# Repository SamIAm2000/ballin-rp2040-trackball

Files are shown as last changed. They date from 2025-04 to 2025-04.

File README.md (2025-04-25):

# ballin

**An open-source 4-button USB trackball powered by the RP2040.**

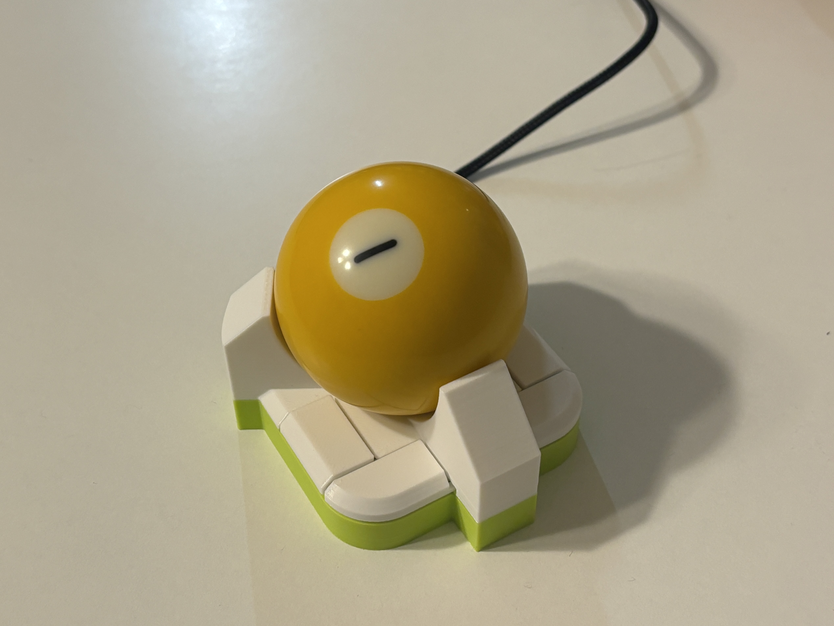
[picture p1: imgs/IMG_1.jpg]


Uses [Jacek Fedorynski's](https://github.com/jfedor2) original PMW3360 trackball firmware and PCB [RP2040+PMW3360](https://github.com/jfedor2/rp2040-pmw3360)

3D models remixed from [here](https://www.printables.com/model/267954-trackball-15de/comments)

The four buttons map to Left Mouse Button, Right Mouse Button, Mouse 4, and Mouse 5. The original model only had 2 buttons, which was not adequate to implement scrolling and swiping functionality on top of the basic left and right clicking.

With the addition of two other buttons, you can map software on your computer to enable scrolling and swiping behaviors when you hold certain mouse buttons. I'm personally a fan of using [Mac Mouse Fix](https://github.com/noah-nuebling/mac-mouse-fix) on all my Mac computers to map Mouse 5 to scrolling when dragged, and Mouse 4 to the 3 fingered swipe that allows you to switch between desktops and spaces and mission control. 

Alternatively, if you want hardware scrolling programmed on the trackball instead of your computer, you can also modify the source code for the trackball. 

## Fabrication
Requires:

- 57.2mm billiard ball
- PMW3360 optical sensor
- PCB from here: https://github.com/jfedor2/rp2040-pmw3360
- 4 micro switches for mice
- 3 2.5mm zirconium oxide (or silicon nitride) bearing balls
- 2 M2x5 screws for securing the switch plates to base 
- 4 M3x4 screws for securing PCB to base
- 3 M3x12 flat head screws
- USB cable *Note: this should be a USB-A cable with the standard 4 wires. Using a USB-C cable might work, but since USB-C generally relies on a handshake before providing power, the trackball would not directly work if you plugged it into your computer with a USB-C cord unless you have a dongle in between.*

### 3D printing
I 3D printed the parts at .20 layer height, no supports needed. I used 40% sparse infill for the top part to get some rigidity and heft. The base I printed at standard 15% sparse infill. 

For the plates that hold the micro switchees, depending on your 3D printer's tolerances, the holes might not be big enough to fit the micro switch legs. I would suggest to first try widening them with some tweezers, if that doesn't work, adjust the X-Y hole compensation by + .1mm maybe. It's better for the holes to be tight and grip onto the switches well than to be too loose and have your switches wobble around. 

### Soldering button pins
Another thing to note is which pins on the PCB you solder your mouse buttons to. In the current compiled trackball.uf2, I have the pins for the buttons defined as thus below. If you use different pins, you would need to modify this code in [code/src/trackball.c](https://github.com/SamIAm2000/ballin-rp2040-trackball/blob/main/code/src/trackball.c)
```
#define TOP_LEFT 16 // Mouse 5
#define TOP_RIGHT 28 // Mouse 4
#define BOTTOM_LEFT 17 // Mouse 1
#define BOTTOM_RIGHT 26 // Mouse 2
```

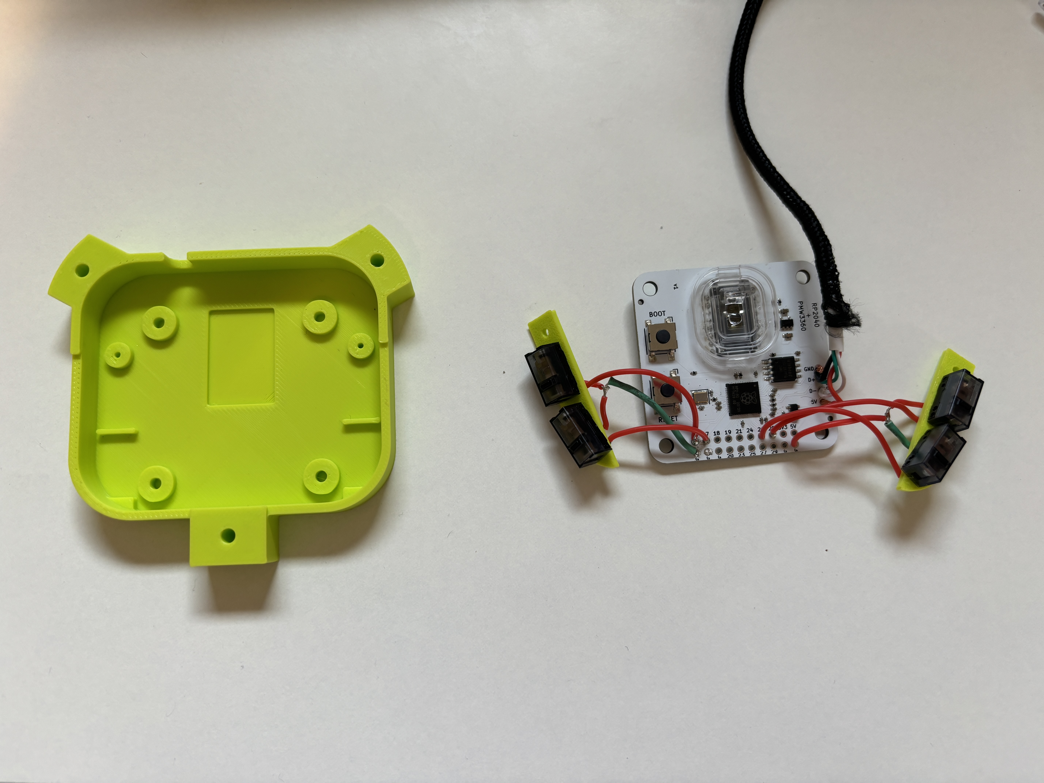
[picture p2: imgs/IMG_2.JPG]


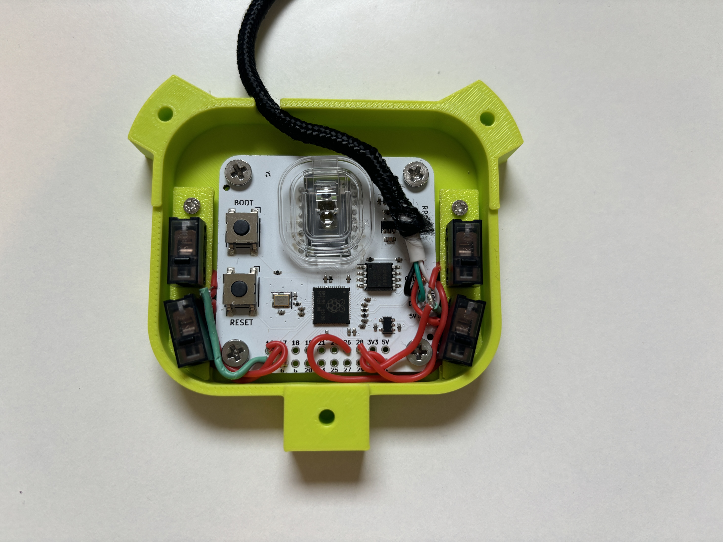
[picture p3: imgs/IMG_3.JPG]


## Compilation

You need Python and CMake installed. 

Once you've cloned this repository, run these commands in the ./code folder to create a build directory and compile.
```
mkdir build
cd build
cmake ..
make
```
The compiled file will be the `trackball.uf2` in the ./code/build/ folder.

## Flashing
To upload the compiled trackball.uf2 file from your computer to the trackball, plug in the USB cable from the trackball into your computer and hold boot, then press reset, then let go of both buttons. The trackball should appear in your list of devices. Drag and drop the .uf2 file on to the trackball.

## Demo
https://github.com/user-attachments/assets/3003e133-2ebc-4bb3-9a59-b019c4e8687f

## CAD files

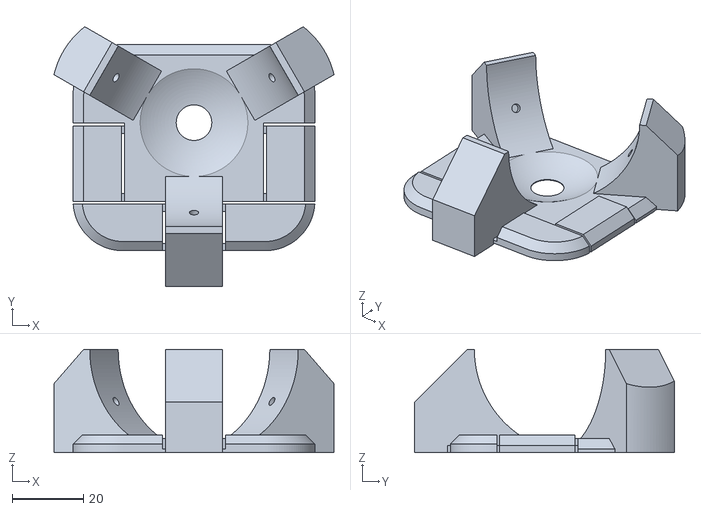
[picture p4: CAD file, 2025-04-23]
3d_models/ballin_top.stl
78.7 x 73.0 x 29.0

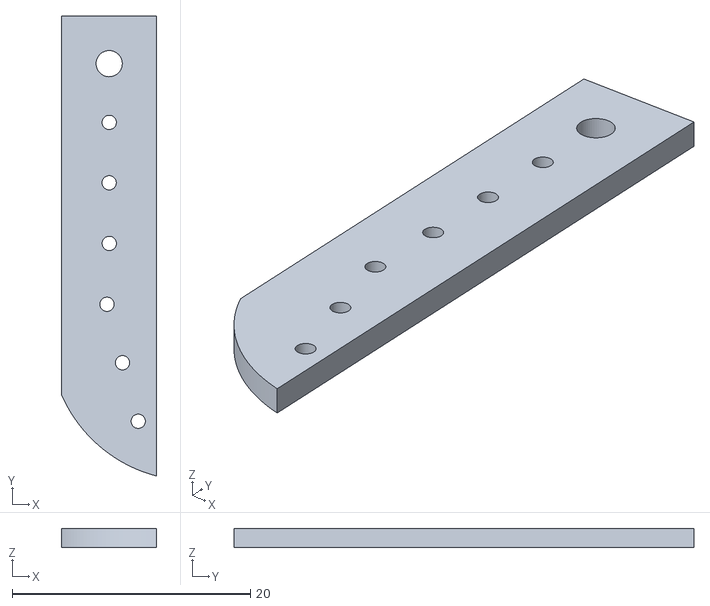
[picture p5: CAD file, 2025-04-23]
3d_models/ballin_plate.stl
7.97 x 38.6 x 1.60

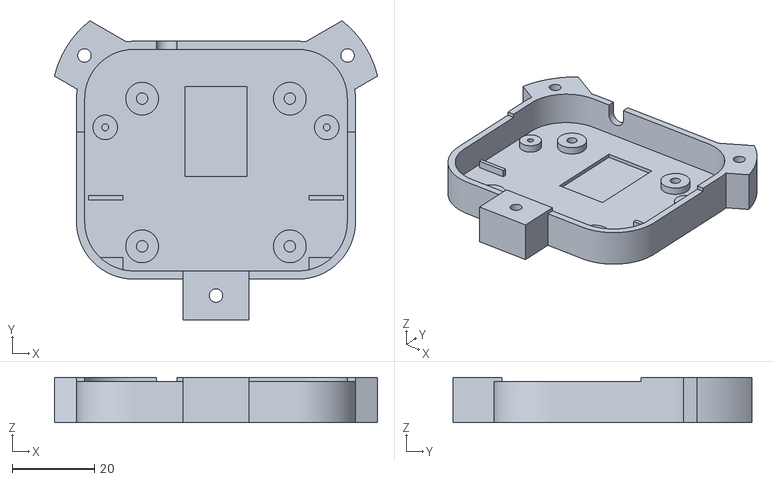
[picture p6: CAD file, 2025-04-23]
3d_models/ballin_base.stl
78.7 x 73.0 x 11.0

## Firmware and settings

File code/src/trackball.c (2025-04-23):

/*
 * The MIT License (MIT)
 *
 * Copyright (c) 2021 Jacek Fedorynski
 * Copyright (c) 2019 Ha Thach (tinyusb.org)
 *
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
 */

#include <stdlib.h>
#include <stdio.h>
#include <string.h>

#include "bsp/board.h"
#include "tusb.h"

#include "pico/stdlib.h"

#include "hardware/gpio.h"

#include "pmw3360.h"

#define TOP_LEFT 16 // Mouse 5
#define TOP_RIGHT 28 // Mouse 4
#define BOTTOM_LEFT 17 // Mouse 1
#define BOTTOM_RIGHT 26 // Mouse 2

// These IDs are bogus. If you want to distribute any hardware using this,
// you will have to get real ones.
#define USB_VID 0xCAFE
#define USB_PID 0xBABA

tusb_desc_device_t const desc_device = {
    .bLength = sizeof(tusb_desc_device_t),
    .bDescriptorType = TUSB_DESC_DEVICE,
    .bcdUSB = 0x0200,
    .bDeviceClass = 0x00,
    .bDeviceSubClass = 0x00,
    .bDeviceProtocol = 0x00,
    .bMaxPacketSize0 = CFG_TUD_ENDPOINT0_SIZE,

    .idVendor = USB_VID,
    .idProduct = USB_PID,
    .bcdDevice = 0x0100,

    .iManufacturer = 0x01,
    .iProduct = 0x02,
    .iSerialNumber = 0x00,

    .bNumConfigurations = 0x01};

uint8_t const desc_hid_report[] = {
    0x05, 0x01,       // USAGE_PAGE (Generic Desktop)
    0x09, 0x02,       // USAGE (Mouse)
    0xA1, 0x01,       // COLLECTION (Application)
    0x09, 0x01,       //   USAGE (Pointer)
    0xA1, 0x00,       //   COLLECTION (Physical)
    0x05, 0x09,       //     USAGE_PAGE (Button)
    0x19, 0x01,       //     USAGE_MINIMUM (1)
    0x29, 0x05,       //     USAGE_MAXIMUM (5)     
    0x15, 0x00,       //     LOGICAL_MINIMUM (0)
    0x25, 0x01,       //     LOGICAL_MAXIMUM (1)
    0x95, 0x05,       //     REPORT_COUNT (5)
    0x75, 0x01,       //     REPORT_SIZE (1)
    0x81, 0x02,       //     INPUT (Data,Var,Abs)
    0x95, 0x01,       //     REPORT_COUNT (1)
    0x75, 0x03,       //     REPORT_SIZE (3)       
    0x81, 0x03,       //     INPUT (Const,Var,Abs)
    0x05, 0x01,       //     USAGE_PAGE (Generic Desktop)
    0x09, 0x30,       //     USAGE (X)
    0x09, 0x31,       //     USAGE (Y)
    0x16, 0x00, 0x80, //     LOGICAL_MINIMUM(-32768)
    0x26, 0xff, 0x7f, //     LOGICAL_MAXIMUM(32767)
    0x75, 0x10,       //     REPORT_SIZE (16)
    0x95, 0x02,       //     REPORT_COUNT (2)
    0x81, 0x06,       //     INPUT (Data,Var,Rel)
    0xC0,             //   END_COLLECTION
    0xC0              // END COLLECTION
};

#define CONFIG_TOTAL_LEN (TUD_CONFIG_DESC_LEN + TUD_HID_DESC_LEN)
#define EPNUM_HID 0x81

uint8_t const desc_configuration[] = {
    // Config number, interface count, string index, total length, attribute, power in mA
    TUD_CONFIG_DESCRIPTOR(1, 1, 0, CONFIG_TOTAL_LEN, 0, 100),

    // Interface number, string index, protocol, report descriptor len, EP In address, size & polling interval
    TUD_HID_DESCRIPTOR(0, 0, HID_ITF_PROTOCOL_NONE, sizeof(desc_hid_report), EPNUM_HID, CFG_TUD_HID_EP_BUFSIZE, 1)};

char const *string_desc_arr[] = {
    (const char[]){0x09, 0x04}, // 0: is supported language is English (0x0409)
    "Trackball",                // 1: Manufacturer
    "Trackball",                // 2: Product
};

// HID report
typedef struct __attribute__((packed))
{
    uint8_t buttons;
    int16_t dx;
    int16_t dy;
} hid_report_t;

hid_report_t report;

void hid_task(void)
{
    int16_t dx;
    int16_t dy;

    if (!tud_hid_ready())
    {
        return;
    }

    pmw3360_get_deltas(&dx, &dy);

    report.dx = dx;
    report.dy = -dy;

    report.buttons = 0;

    if (!gpio_get(BOTTOM_LEFT))
        report.buttons |= 0x01; // Bit 0 = Left Click
    if (!gpio_get(BOTTOM_RIGHT))
        report.buttons |= 0x02; // Bit 1 = Right Click
    // if (!gpio_get(PIN_MMB))   report.buttons |= 0x04; // Bit 2 = Middle Click
    if (!gpio_get(TOP_RIGHT))
        report.buttons |= 0x08; // Bit 3 = Mouse Button 4 - 3 finger swipe
    if (!gpio_get(TOP_LEFT))
        report.buttons |= 0x10; // Bit 4 = Mouse Button 5 - scroll

    tud_hid_report(0, &report, sizeof(report));
}

void pin_init(uint pin)
{
    gpio_init(pin);
    gpio_set_dir(pin, GPIO_IN);
    gpio_pull_up(pin);
}

void pins_init(void)
{
    pin_init(TOP_LEFT);
    pin_init(TOP_RIGHT);
    pin_init(BOTTOM_LEFT);
    pin_init(BOTTOM_RIGHT);
}

void report_init(void)
{
    memset(&report, 0, sizeof(report));
}

int main(void)
{
    stdio_init_all();
    board_init();
    pins_init();
    pmw3360_init();
    report_init();
    tusb_init();

    pmw3360_set_cpi(800);

    while (1)
    {
        tud_task(); // tinyusb device task
        hid_task();
    }

    return 0;
}

// Invoked when received GET DEVICE DESCRIPTOR
// Application return pointer to descriptor
uint8_t const *tud_descriptor_device_cb(void)
{
    return (uint8_t const *)&desc_device;
}

// Invoked when received GET HID REPORT DESCRIPTOR
// Application return pointer to descriptor
// Descriptor contents must exist long enough for transfer to complete
uint8_t const *tud_hid_descriptor_report_cb(uint8_t itf)
{
    return desc_hid_report;
}

// Invoked when received GET_REPORT control request
// Application must fill buffer report's content and return its length.
// Return zero will cause the stack to STALL request
uint16_t tud_hid_get_report_cb(uint8_t itf, uint8_t report_id, hid_report_type_t report_type, uint8_t *buffer, uint16_t reqlen)
{
    return 0;
}

// Invoked when received SET_REPORT control request or
// received data on OUT endpoint ( Report ID = 0, Type = 0 )
void tud_hid_set_report_cb(uint8_t itf, uint8_t report_id, hid_report_type_t report_type, uint8_t const *buffer, uint16_t bufsize)
{
}

// Invoked when received GET CONFIGURATION DESCRIPTOR
// Application return pointer to descriptor
// Descriptor contents must exist long enough for transfer to complete
uint8_t const *tud_descriptor_configuration_cb(uint8_t index)
{
    return desc_configuration;
}

static uint16_t _desc_str[32];

// Invoked when received GET STRING DESCRIPTOR request
// Application return pointer to descriptor, whose contents must exist long enough for transfer to complete
uint16_t const *tud_descriptor_string_cb(uint8_t index, uint16_t langid)
{
    uint8_t chr_count;

    if (index == 0)
    {
        memcpy(&_desc_str[1], string_desc_arr[0], 2);
        chr_count = 1;
    }
    else
    {
        // Note: the 0xEE index string is a Microsoft OS 1.0 Descriptors.
        // https://docs.microsoft.com/en-us/windows-hardware/drivers/usbcon/microsoft-defined-usb-descriptors

        if (!(index < sizeof(string_desc_arr) / sizeof(string_desc_arr[0])))
            return NULL;

        const char *str = string_desc_arr[index];

        // Cap at max char
        chr_count = strlen(str);
        if (chr_count > 31)
            chr_count = 31;

        // Convert ASCII string into UTF-16
        for (uint8_t i = 0; i < chr_count; i++)
        {
            _desc_str[1 + i] = str[i];
        }
    }

    // first byte is length (including header), second byte is string type
    _desc_str[0] = (TUSB_DESC_STRING << 8) | (2 * chr_count + 2);

    return _desc_str;
}

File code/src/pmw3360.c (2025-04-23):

// derived from https://github.com/mrjohnk/PMW3360DM-T2QU

#include "hardware/gpio.h"
#include "hardware/spi.h"

#include "srom.h"

#include <pico/time.h>

#define SPI_PORT spi0

#define PIN_MISO 4
#define PIN_CS   9
#define PIN_SCK  2
#define PIN_MOSI 3

// Registers
#define Product_ID  0x00
#define Revision_ID 0x01
#define Motion  0x02
#define Delta_X_L 0x03
#define Delta_X_H 0x04
#define Delta_Y_L 0x05
#define Delta_Y_H 0x06
#define SQUAL 0x07
#define Raw_Data_Sum  0x08
#define Maximum_Raw_data  0x09
#define Minimum_Raw_data  0x0A
#define Shutter_Lower 0x0B
#define Shutter_Upper 0x0C
#define Control 0x0D
#define Config1 0x0F
#define Config2 0x10
#define Angle_Tune  0x11
#define Frame_Capture 0x12
#define SROM_Enable 0x13
#define Run_Downshift 0x14
#define Rest1_Rate_Lower  0x15
#define Rest1_Rate_Upper  0x16
#define Rest1_Downshift 0x17
#define Rest2_Rate_Lower  0x18
#define Rest2_Rate_Upper  0x19
#define Rest2_Downshift 0x1A
#define Rest3_Rate_Lower  0x1B
#define Rest3_Rate_Upper  0x1C
#define Observation 0x24
#define Data_Out_Lower  0x25
#define Data_Out_Upper  0x26
#define Raw_Data_Dump 0x29
#define SROM_ID 0x2A
#define Min_SQ_Run  0x2B
#define Raw_Data_Threshold  0x2C
#define Config5 0x2F
#define Power_Up_Reset  0x3A
#define Shutdown  0x3B
#define Inverse_Product_ID  0x3F
#define LiftCutoff_Tune3  0x41
#define Angle_Snap  0x42
#define LiftCutoff_Tune1  0x4A
#define Motion_Burst  0x50
#define LiftCutoff_Tune_Timeout 0x58
#define LiftCutoff_Tune_Min_Length  0x5A
#define SROM_Load_Burst 0x62
#define Lift_Config 0x63
#define Raw_Data_Burst  0x64
#define LiftCutoff_Tune2  0x65

void cs_select() {
    asm volatile ("nop \n nop \n nop");
    gpio_put(PIN_CS, 0);        // Active low
    asm volatile ("nop \n nop \n nop");
}

void cs_deselect() {
    asm volatile ("nop \n nop \n nop");
    gpio_put(PIN_CS, 1);
    asm volatile ("nop \n nop \n nop");
}

uint8_t read_register(uint8_t reg_addr) {
    cs_select();

    // send adress of the register, with MSBit = 0 to indicate it's a read
    uint8_t x = reg_addr & 0x7f;
    spi_write_blocking(SPI_PORT, &x, 1);
    sleep_us(100);              // tSRAD
    // read data
    uint8_t data;
    spi_read_blocking(SPI_PORT, 0, &data, 1);

    sleep_us(1);                // tSCLK-NCS for read operation is 120ns
    cs_deselect();
    sleep_us(19);               // tSRW/tSRR (=20us) minus tSCLK-NCS

    return data;
}

void write_register(uint8_t reg_addr, uint8_t data) {
    cs_select();

    // send adress of the register, with MSBit = 1 to indicate it's a write
    uint8_t x = reg_addr | 0x80;
    spi_write_blocking(SPI_PORT, &x, 1);
    // send data
    spi_write_blocking(SPI_PORT, &data, 1);

    sleep_us(20);               // tSCLK-NCS for write operation
    cs_deselect();
    sleep_us(100);              // tSWW/tSWR (=120us) minus tSCLK-NCS. Could be shortened, but is looks like a safe lower bound 
}

void upload_firmware() {
    // send the firmware to the chip, cf p.18 of the datasheet

    // Write 0 to Rest_En bit of Config2 register to disable Rest mode.
    write_register(Config2, 0x20);

    // write 0x1d in SROM_enable reg for initializing
    write_register(SROM_Enable, 0x1d);

    // wait for more than one frame period
    sleep_ms(10);               // assume that the frame rate is as low as 100fps... even if it should never be that low

    // write 0x18 to SROM_enable to start SROM download
    write_register(SROM_Enable, 0x18);

    // write the SROM file (=firmware data) 
    cs_select();
    uint8_t data = SROM_Load_Burst | 0x80; // write burst destination adress
    spi_write_blocking(SPI_PORT, &data, 1);
    sleep_us(15);

    // send all bytes of the firmware
    for (int i = 0; i < firmware_length; i++) {
        spi_write_blocking(SPI_PORT, &(firmware_data[i]), 1);
        sleep_us(15);
    }

    // Read the SROM_ID register to verify the ID before any other register reads or writes.
    read_register(SROM_ID);

    // Write 0x00 to Config2 register for wired mouse or 0x20 for wireless mouse design.
    write_register(Config2, 0x00);

    // set initial CPI resolution
    write_register(Config1, 0x15);

    cs_deselect();
}

void perform_startup(void) {
    cs_deselect();              // ensure that the serial port is reset
    cs_select();                // ensure that the serial port is reset
    cs_deselect();              // ensure that the serial port is reset
    write_register(Power_Up_Reset, 0x5a);       // force reset
    sleep_ms(50);               // wait for it to reboot
    // read registers 0x02 to 0x06 (and discard the data)
    read_register(Motion);
    read_register(Delta_X_L);
    read_register(Delta_X_H);
    read_register(Delta_Y_L);
    read_register(Delta_Y_H);
    // upload the firmware
    upload_firmware();
    sleep_ms(10);
}

void pmw3360_set_cpi(unsigned int cpi) {
    int cpival = (cpi / 100) - 1;
    cs_select();
    write_register(Config1, cpival);
    cs_deselect();
}

void pmw3360_get_deltas(int16_t * dx, int16_t * dy) {
    // write 0x01 to Motion register and read from it to freeze the motion values and make them available
    write_register(Motion, 0x01);
    read_register(Motion);

    *dx = (int16_t) (read_register(Delta_X_H) << 8 | read_register(Delta_X_L));
    *dy = (int16_t) (read_register(Delta_Y_H) << 8 | read_register(Delta_Y_L));
}

void pmw3360_init() {
    gpio_set_function(PIN_MISO, GPIO_FUNC_SPI);
    gpio_set_function(PIN_SCK, GPIO_FUNC_SPI);
    gpio_set_function(PIN_MOSI, GPIO_FUNC_SPI);

    gpio_init(PIN_CS);
    gpio_set_dir(PIN_CS, GPIO_OUT);
    gpio_put(PIN_CS, 1);

    spi_init(SPI_PORT, 500000);
    spi_set_format(SPI_PORT, 8, 1, 1, SPI_MSB_FIRST);

    perform_startup();
}

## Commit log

2025-04-23 initial commit docs
    [ballin_base.stl, ballin_plate.stl, ballin_top.stl]
2025-04-23 updated top 3d model
    [ballin_top.stl]
